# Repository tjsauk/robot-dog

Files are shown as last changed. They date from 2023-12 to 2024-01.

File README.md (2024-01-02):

# robot-dog
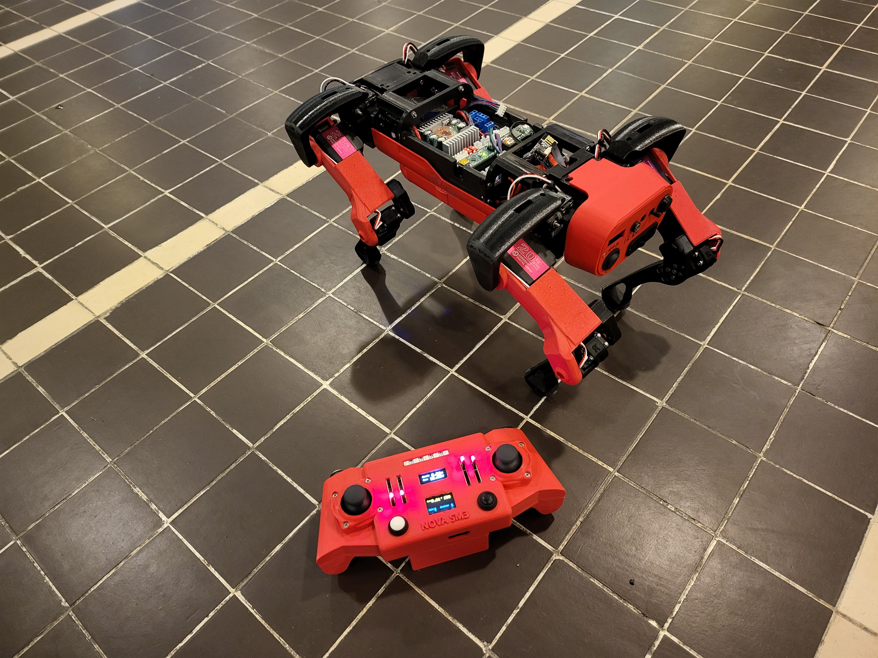
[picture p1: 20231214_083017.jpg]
The robot and the remote

Code and the documentation pdf contain spelling errors.<br>
Comments in code are partly in english and partly in finnish.<br>

Other than that the simulator works as its supposed to.<br>

Folder muokatut contains some 3D models that I have modified. <br>
-NOVA SM3 Assembly_SM3_Frame_RightTibia muokattu <-- modified tibia for the robot, attachment point for  the servo is changed to better fit the servomotors used.<br>
-cover_updated_for_Chris_Shoulder_muokattu v4 <-- modified the bearing holes to fit the bearings I used.<br>
-SM3_Frame_FrontShoulderOuter paksunnettu <-- part is made thicker and bearing holes deeper to work with the modified frame.<br>
-SM3_Frame_RearShoulderMiddle Paksunnettu levy <-- same as above.<br>
-robottikoiran jetson runko v4 <-- modified main frame part for the robot. It is made to have room for jetson nano and the components in the original design.<br>
-Assembly_Cover_HeadPanel kamera upotus v8 <-- modified the head part so that it has mounting for IMX219-83 Stereo Camera.<br>
-Ass - Speaker v5 v1 <-- is modified so that it fits to the new shoulder frame parts.<br>
-tassumuotti <- mold for casting the paws from silicone
-Paw pressure sensor contains files for the parts and couple of images of the sensors. 
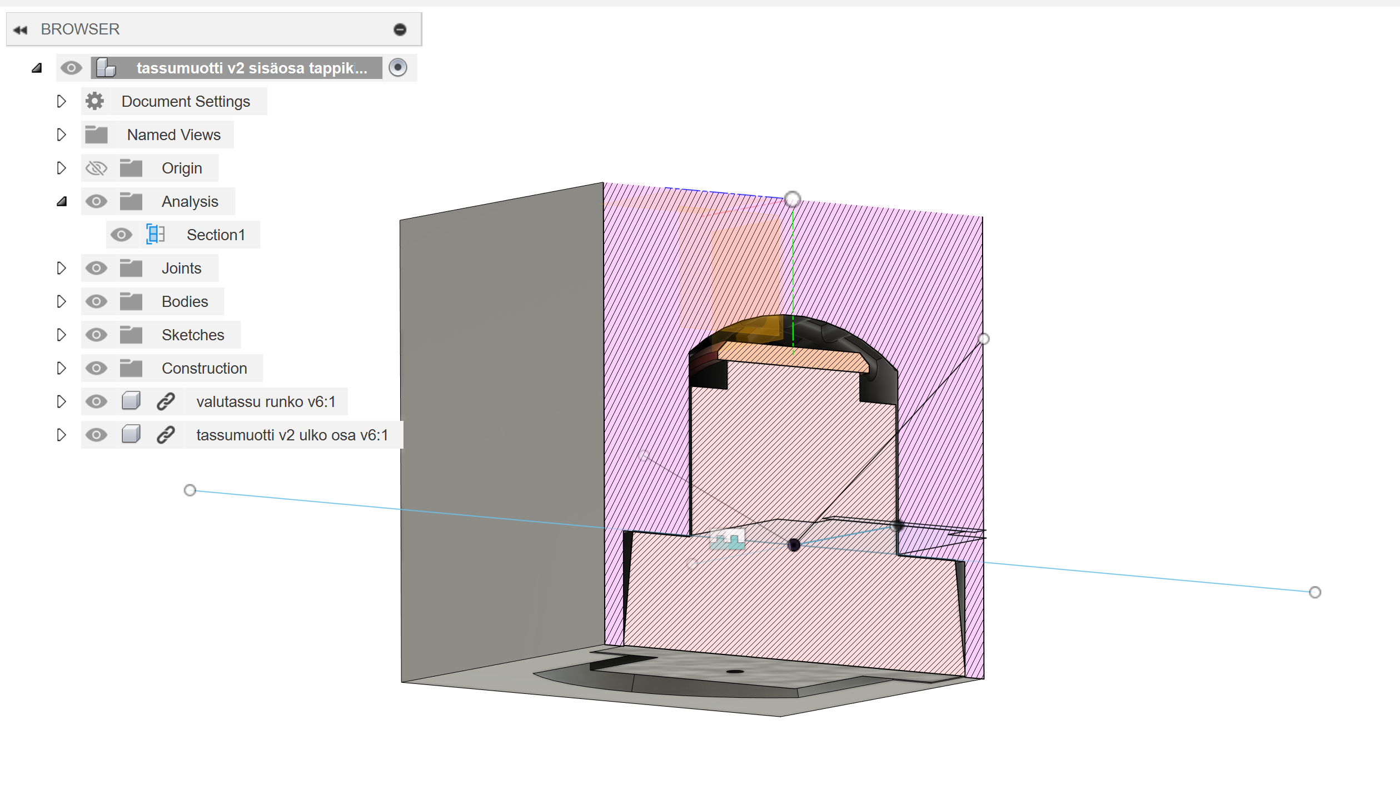
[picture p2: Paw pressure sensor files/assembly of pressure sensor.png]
Assembly of the paw mould

Here is the partnumber for the sensor from digikey 1738-SEN0293-ND

Original design can be found from here:<br>
https://github.com/cguweb-com/Arduino-Projects/tree/main/Nova-SM3<br>

Code is python version of the code that is eventually going to be in the robot. <br>

Python version works as a simulator for the behavior, so it would be easyer to implement new code with out breaking anything.<br>

dynamic_balancing_v0.1 contains the teensy 4.0 code that has all the basic functionality. It can communicate with the remote and move accordingly. The code does dynamic balancing while walking but the parameters of that are in a need of finetuning at the time this code was uploaded. <br>

To set up the code in your system follow these steps. <br>
Comment everything off from the void loop. Start by finding the zero position just by adjusting values in these lines <br>
body.mRightFront.mTibia.Attach(15, SERVO_35KG, 220.0, 10.0,89.3). Zero position is a position where coaxes are aligned and in 90 degree angle relative to the body and the axis of tibia and femur align in a straigh line going down from the body toward the ground. Basicly in zero position the robot stand with all its legs fully extended. Find this position by changing the first degree value in Attach commands. Then after the correct degrees are found its time to move those values in to the last position in the attach command. Then the first values are used to find good boot up position for the robot. <br>
The syntax of the attach goes like this body.mRightFront.mTibia.Attach(Pin id of this joint in the motor driver, Type of motor used, Home position in degrees, Home position offset,Zero position in degrees)<br>
After the zero and home is set up you can run the code inside the void loop. To make the robot move correctly you need to finetune the zero positions by putting the robot in to a walking position and compare the values in myconfig to the robots current position. Fine tune the degrees until the robot matches to the myconfig values as closely as possible, start from coax joints, continue with femurs and finally tibia. Tibia can be used to eaven out the weight distribution of the robot. <br>
To make the robot resbond to the remote you need to have the same remote or set up your own. The remote im using can be found here <br>
https://github.com/cguweb-com/Arduino-Projects/tree/cb5a4712f65acdd1623183609f027163f564fcbd/Nova-SM3/Remote%20Control <br>
My remote code v0.1 matches this teensy code so it should work with little effort. <br>

dynamic_balancing_v0.2 works with remote adjusted balancing parameters. Remote code 0.2 matches this version. <br>

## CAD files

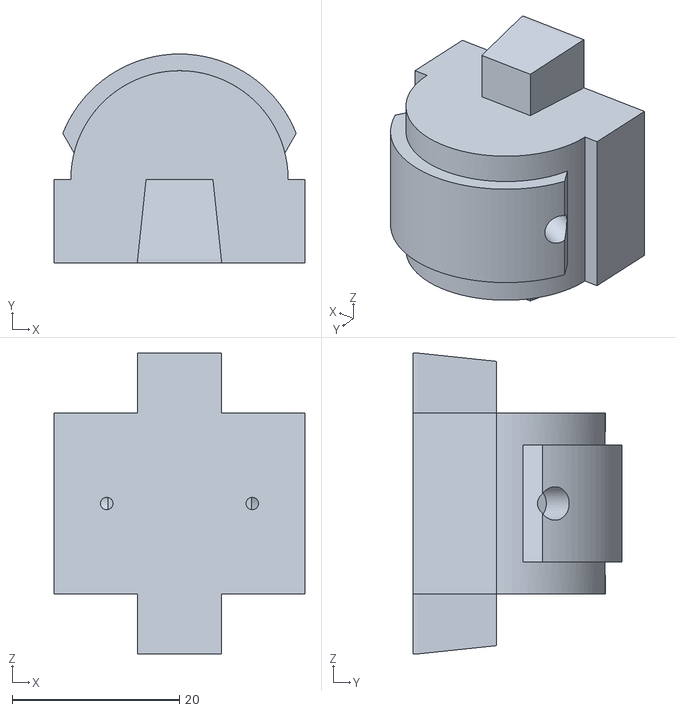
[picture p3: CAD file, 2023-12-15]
muokatut/tassumuotti v2 sisäosa tappikiinnitys v2.stl
30.0 x 25.0 x 36.0

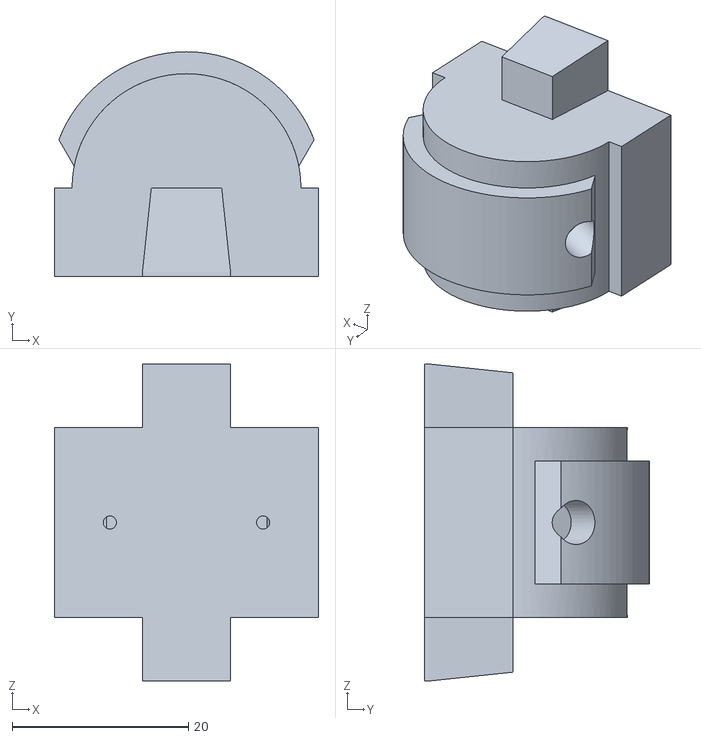
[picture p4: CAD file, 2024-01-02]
Paw pressure sensor files/tassumuotti v2 sisäosa tappikiinnitys liimausjigi v3.stl
30.0 x 25.5 x 36.0

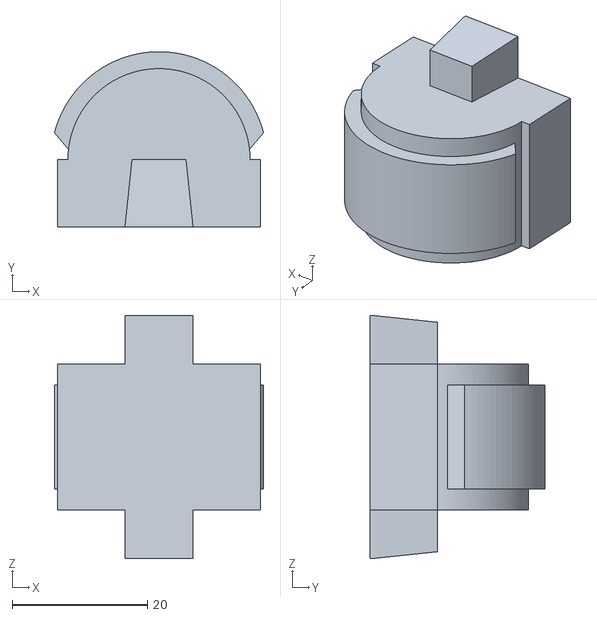
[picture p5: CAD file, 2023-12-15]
muokatut/tassumuotti v2 sisäosa v4.stl
31.0 x 26.0 x 36.0

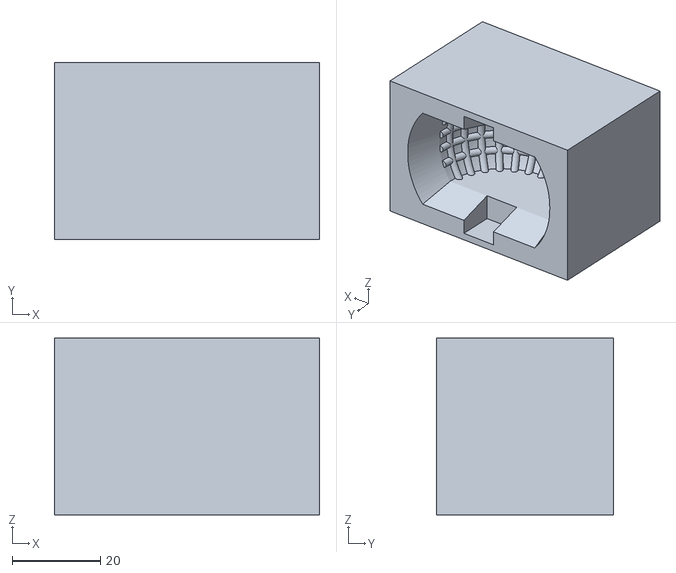
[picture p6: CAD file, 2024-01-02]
Paw pressure sensor files/tassumuotti ulko osa urilla.stl
60.0 x 40.0 x 40.0

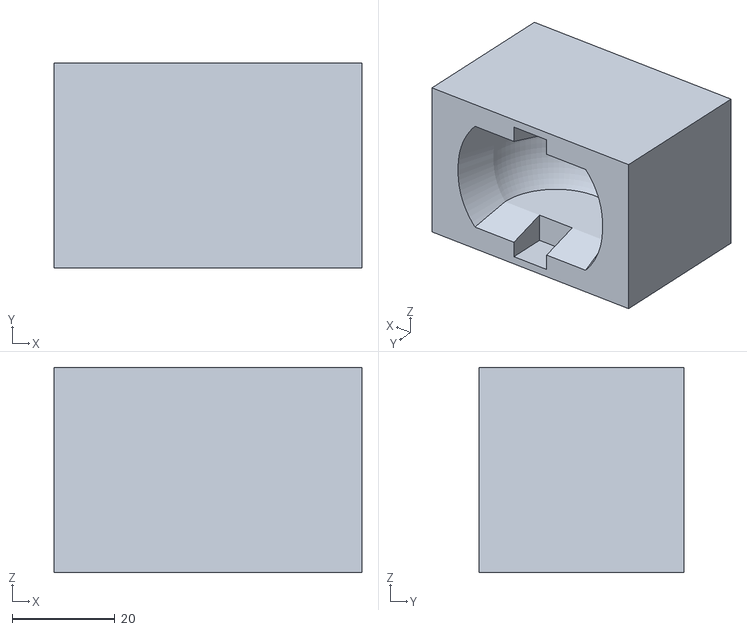
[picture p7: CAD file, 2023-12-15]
muokatut/tassumuotti v2 ulko osa v2.stl
60.0 x 40.0 x 40.0

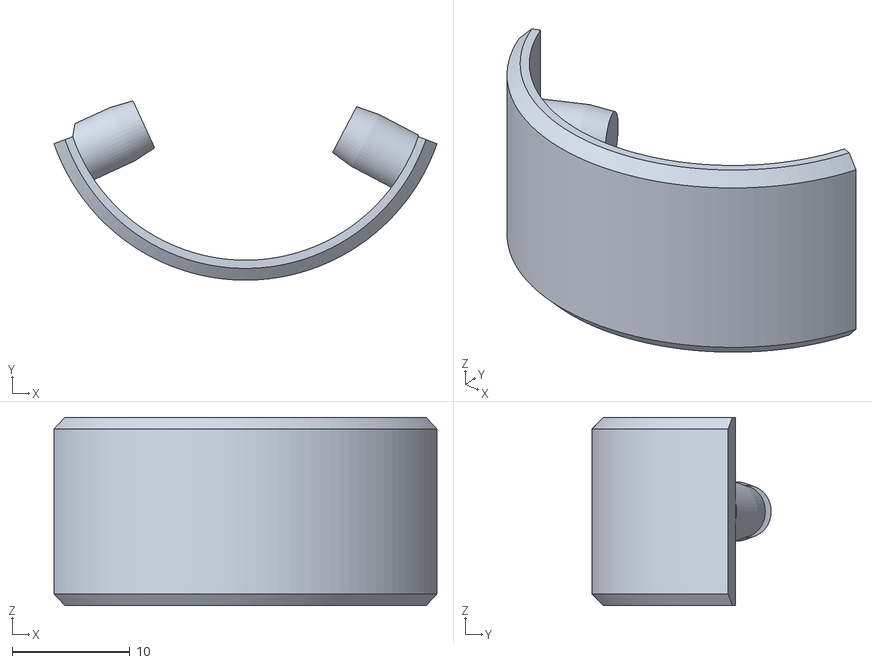
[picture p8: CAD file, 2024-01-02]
Paw pressure sensor files/valutassu runko TPU.stl
32.5 x 15.2 x 16.0

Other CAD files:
Paw pressure sensor files/tassumuotti sisäosa tappikiinnitys valuversio.stl
muokatut/Ass - Speaker v5 muokattu.f3d
muokatut/NOVA SM3 Assembly_SM3_Frame_RightTibia muokattu.f3d
muokatut/SM3_Frame_FrontShoulderOuter paksunnettu.f3d
muokatut/SM3_Frame_RearShoulderMiddle Paksunnettu levy.f3d
muokatut/robottikoiran jetson runko v4.f3d

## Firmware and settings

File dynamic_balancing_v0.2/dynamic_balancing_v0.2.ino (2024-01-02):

#include "MyAsyncServo.h"
#include "MyLeg.h"
#include "MyBody.h"
#include "MyLog.h"
#include <RF24.h>
#include "MPU6050_conf.h"

//NovaSMRemote NRF24 controller
//Pin wiring for Teensy 4.0:
//  pin 9 -> CE pin
//  pin 10 -> CSN pin
//  pin 13 -> SCK pin
//  pin 11 -> MOSI pin
//  pin 12 -> MISO pin
//  pin xx -> IRQ pin (unused)
// instantiate an object for the nRF24L01 transceiver
RF24 nrf_radio(9, 10);
unsigned int nrfInterval = 50;
unsigned long lastNRFUpdate = 0;
unsigned int remoteInterval = 50;
unsigned long lastRemoteUpdate = 0;

uint8_t address[2][6] = {"1Node", "2Node"};
bool radioNumber = 1; // 0 uses address[0] to transmit, 1 uses address[1] to transmit
const int data_num = 14;          //bytes of data to receive
bool rc_resp;
uint8_t rc_data[data_num] = {     //receive data array
  0, 0, 0, 0,                     //btn1, btn2, btn3, btn4
  0, 0,                           //sel2, sel1
  0, 0, 0, 0,                     //p1, p4, p2 , p3 index 6-9
  0, 0, 0, 0                      //lx, ly, rx, ry index 10-13
};
uint8_t tm_data[data_num] = {     //transmit data array
  0, 0, 0,                        //battery, spd, Y
  0, 0, 0,                        //x compensate, y compensate, ??
  1, 0, 0, 0,                     //Current gate, Standing up, ?? , ??
  0, 0, 0, 0                      //
};

#define BATT_MONITOR A1

// MPU6050 sensor I2C address
const int MPU = 0x68;

// Time interval in milliseconds for MPU updates
unsigned int mpuInterval = 10;
unsigned int mpuInterval_prev = 400;

// Timestamp for the last MPU update
unsigned long lastMPUUpdate = 0;

// Variables for storing the current and previous roll, pitch, and yaw values
float mroll, mpitch, myaw;
float mroll_prev, mpitch_prev, myaw_prev;

// Variables for accelerometer angles
float accAngleX, accAngleY;

// Variables for gyro angles
float gyroAngleX, gyroAngleY, gyroAngleZ;

// Base offset values for MPU
float mpu_mroll = 0.00;
float mpu_mpitch = 0.00;
float mpu_myaw = 0.00;

// Threshold value for triggering MPU changes
float mpu_trigger_thresh = 0.05;

// Timing variables for handling the sensor's updates
float elapsedTime, currentTime, previousTime;

// Flag to check if MPU is active
int mpu_is_active = 1;

// Counter variable for MPU
int mpu_c = 0;

// Instantiate the body object

MyBody body;

//----------------------------

// y akseli on pystyssä z sivuttain ja x kulkusuunnassa
void setup() {
  my_log(MYLOG_INFO, "Application started");
  

  // Attach(PWM_ID, SERVO_TYPE, HOME_DEGREE, DEGREE_CORRECTION,ZERO_DEGREE)
  //To make inverse kinematics work, change motor degree ranges correct at myasyncservo.cpp file
  //home degrees and correction term define the position the robot starts at. Start finding from the middle of your servos movement
  //zero degrees is the degree position where legs are fully extended and straight down from the body. Start allso from center.
  //Fine tune the zero degrees calibration by measuring that coax motors are in 90 degree angle relative to the frame. when robot is in standing position
  //femurs need to be calibrated next so that rear and front legs go straight relative to each other
  //then tibia is calibrated so that the standing position height is correct. Finally femur needs to be tuned so that the paw position
  //is correct measurement wise. Remember to make sure all slack in the joints is correctly positioned aka legs are under weight
  //--------------------------------------------------------
  body.mRightFront.mTibia.Attach(15, SERVO_35KG, 220.0, 10.0,89.3);//posi akselin suuntaan myötäpäivään 83
  body.mRightFront.mFemur.Attach(14, SERVO_20KG, 100.0, 0.0,170.8);
  body.mRightFront.mCoax.Attach(13, SERVO_20KG, 135.0, 6.0,139.0);//positive drives legs end to right
 

  body.mRightRear.mTibia.Attach(6, SERVO_35KG, 220.0, 10.0,90.0);//pos aks suun myöt päiv
  body.mRightRear.mFemur.Attach(5, SERVO_20KG, 100.0, -15.0,172.3);//smaller number lifts knee up
  body.mRightRear.mCoax.Attach(4, SERVO_20KG, 135.0, 3.0,139.0);//positive drives legs end to right
  
  
  body.mLeftFront.mTibia.Attach(9, SERVO_35KG, 220.0, 3.0,87.9);//suurempi on enemmän koukussa. suora koti oli 85. koukku koti oli 220 ja 3
  body.mLeftFront.mFemur.Attach(10, SERVO_20KG, 100.0, -20.0,172.9);//pienempi on takana ylhäällä. suora koti oli 110. koukku koti oli 100 ja -20
  body.mLeftFront.mCoax.Attach(11, SERVO_20KG, 135.0, -9.0,135.0);//positive drives legs end to right
  
  
  body.mLeftRear.mTibia.Attach(2, SERVO_35KG, 220.0, 3.0,85.1);//nega aks suunt myötäpäivään
  body.mLeftRear.mFemur.Attach(1, SERVO_20KG, 100.0, -26.0,172.2);//110 muuttamaton
  body.mLeftRear.mCoax.Attach(0, SERVO_20KG, 135.0, -12.0,138.0);//positive drives legs end to right
 

  
  // PHYSICAL LIMITS IN DEGREES 
  //----------------------------
  body.mLeftFront.mTibia.SetLimits(80.0, 270.0); 
  body.mLeftRear.mTibia.SetLimits(80.0, 270.0); 
  body.mRightFront.mTibia.SetLimits(80.0, 270.0); 
  body.mRightRear.mTibia.SetLimits(80.0, 270.0); 
  
  body.mLeftFront.mFemur.SetLimits(0.0, 270.0);
  body.mRightFront.mFemur.SetLimits(0.0, 270.0);
  body.mLeftRear.mFemur.SetLimits(0.0, 270.0);
  body.mRightRear.mFemur.SetLimits(0.0, 270.0);

  body.mLeftFront.mCoax.SetLimits(50.0, 170.0);
  body.mRightFront.mCoax.SetLimits(50.0, 170.0);
  body.mLeftRear.mCoax.SetLimits(50.0, 170.0);
  body.mRightRear.mCoax.SetLimits(50.0, 170.0);
  
  pinMode(LED_BUILTIN, OUTPUT);
  
  // Put synchronously body in home
 
  body.home();

  delay(2000);

    //init NRF24 wireless
  
    if (!nrf_radio.begin()) {
      Serial.println(F("radio hardware is not responding!!"));
      while (1) {}
    } else {
      nrf_radio.setPALevel(RF24_PA_LOW);
      nrf_radio.setPayloadSize(sizeof(rc_data));
      nrf_radio.setChannel(124);
      nrf_radio.openReadingPipe(1, address[!radioNumber]);
      nrf_radio.enableAckPayload();
      nrf_radio.startListening();
      nrf_radio.writeAckPayload(1, &tm_data, sizeof(tm_data)); // pre-load data      if (debug8) Serial.println(F("radio hardware is ready and listening!"));
    }

     // Initialize the MPU6050 sensor

    // Start the Wire library and communicate with the MPU6050
    Wire1.begin();

    // Read the WHO_AM_I register to confirm device identity
    uint8_t c = readByte(MPU6050_ADDRESS, WHO_AM_I_MPU6050);
    delay(1000); // Delay for stability

    // Check if the read identity is correct (0x68)
    if (c == 0x68) {
        // Perform a self-test on the MPU6050
        MPU6050SelfTest(SelfTest);

        // Check if self-test values are within acceptable ranges
        if (SelfTest[0] < 1.0f && SelfTest[1] < 1.0f && SelfTest[2] < 1.0f &&
            SelfTest[3] < 1.0f && SelfTest[4] < 1.0f && SelfTest[5] < 1.0f) {
            // Calibrate the gyro and accelerometers and initialize MPU6050 settings
            calibrateMPU6050(gyroBias, accelBias);
            initMPU6050();
        }
    }
}
  
  



void nrf_ack() {

    //set data
    int sensorValue = analogRead(BATT_MONITOR);//in a skale from 0 to 1023
    double voltage = (sensorValue * (3.3 / 1023.00) *(0.985+4.668))/0.985*1.325; 
    tm_data[0] = int(voltage*10);
    //tm_data[0] = 0;//bv;
    //tm_data[1] = 0;//spd;
    tm_data[2] = int(body.getHeight());//sound_vol;
    //tm_data[3] = 0;//move_steps;
    //tm_data[4] = 6;//(step_weight_factor_front * 100);
    //tm_data[5] = 6;//(step_weight_factor_rear * 100);
    //tm_data[6] = 0;//remote_select;
    //tm_data[7] = 3;//start_mode;
    
  
    nrf_radio.writeAckPayload(1, &tm_data, sizeof(tm_data)); // load the payload for the next time
}

bool nrf_check() {
  bool resp = false;
  uint8_t pipe;

  if (nrf_radio.available(&pipe)) {
    uint8_t bytes = nrf_radio.getPayloadSize();
    nrf_radio.read(&rc_data, bytes);
    resp = true;

    //send data as acknowledgement
    nrf_ack();


  }
  lastNRFUpdate = millis();

  return resp;
}

void get_mpu() {

  if(readByte(MPU6050_ADDRESS, INT_STATUS) & 0x01) {  // check if data ready interrupt
    readAccelData(accelCount);  // Read the x/y/z adc values
    getAres();
    
    //Acceleration values in m/s with correction to system coordinates
    // Adjust the axis readings to match the system's coordinate and convert to m/s^2
        ax = -((float)accelCount[0] - accelBias[0]) * aRes * 9.81; // Reverse X-axis and convert to m/s^2
        az = ((float)accelCount[1] - accelBias[1]) * aRes * 9.81;  // Map Y to Z and convert to m/s^2
        ay = -((float)accelCount[2] - accelBias[2]) * aRes * 9.81; // Map Z to Y, invert it and convert to m/s^2

    readGyroData(gyroCount);  // Read the x/y/z adc values
    getGres();
 
    // Adjust the gyroscope axis readings to match the system's coordinate
    gx = -((float)gyroCount[0] * gRes - gyroBias[0]); // Reverse X-axis
    gz = ((float)gyroCount[1] * gRes - gyroBias[1]);  // Map Y to Z
    gy = -((float)gyroCount[2] * gRes - gyroBias[2]); // Map Z to Y and invert


  }  
    
  //on init mpu, save offsets as defaults for resetting MPU position
  if (mpuInterval != mpuInterval_prev){
    mpuInterval = mpuInterval_prev;
    mpu_mroll = mroll;
    mpu_mpitch = mpitch;
    mpu_myaw = myaw;

    
  }

  lastMPUUpdate = millis();
}

void test3(unsigned long now_mills)
{
  static int test_phase = 0;
  static unsigned int wait_until = 1000;
  
 
  if (now_mills < wait_until)
   { return;
   }
  else if (test_phase == 0)
  {
    body.setGait(GAIT_WALK); // select WALK mode GAIT_WALK
    body.GoWalkPosition(now_mills, 900, 0.3); // start stand-up at time delta=0ms then 1000ms pause (the stand-up duration is set to 900ms then 100ms do nothing) 
    //body.GoTestPosition(now_mills, 900, 0.3);
    //GoZeroPosition(unsigned long mills, unsigned long duration, double ramp)
    //body.GoZeroPosition(now_mills, 900, 0.3);
    test_phase++;
    wait_until = now_mills + 3000; // wait 2s (where the movement home->walk position elapse 900ms)
    return;
  }
    else if (test_phase == 1)
  {
    //WalkDirection(double velocity, double degree_x, double  degree_y, double degree_z, double x, double y, double z, double ramp)
    body.WalkDirection(0.04, 0.0, 0, 0, 1, 0, 0, 0.3, 0);//nopeus m/s , x kääntö suunta,y kääntö suunta,zkääntö suunta, x suunnan nopeus 0-1, y korkeus +- kävely asennosta, z nopeus 0-1
   
    
    test_phase++;
    wait_until = now_mills + 50000; // walk for 2s
    return;
  }
    
  
  else if (test_phase == 2)/////////////
  {
    body.WalkDirection(0.25, 0, 0, 0, 0, 0, 0, 0.3 , 2);//last integer 0 means walk or move, 1 is go home 
    body.GoWalkPosition(now_mills, 900, 0.3);
    test_phase++;
    wait_until = now_mills + 1000; // stay stopped for 1s
    return;
  }
  
  
}

double reMapJoystic(double val, double midvalue)
{
  double deadzone = 5;// +- 5 from center
  double result = 0.0;
  
  if (val > (midvalue - deadzone) && val < (midvalue + deadzone)) {
    return 0.0;
  } else if (val > (midvalue + deadzone)) { // from 0 to 1
    double coef = 255 - (midvalue + deadzone); // Range of values from dead zone to high max coefficient converting it to range 0-1
    result = ((double)(val - (midvalue + deadzone))*(1 / coef));
    return result;
  } else {//if (val < (midvalue - deadzone)) 
    result = (double)val * (1.0 / (midvalue - deadzone))-1;
    return result;
  }
}



void loop() {
  static unsigned int last_mills = 0;//Time of next command update
  nrf_check();//receive and send remote data
  get_mpu();
  unsigned long now_mills = millis();//current time
  static int isSitting = 0;
  static int isGivingPaw = 0;
  static int captureIMUzero = 0;
  
    if (now_mills >= last_mills)//time needs to be greater or equal of the set limit
  {
    //Take measurements from gyro when at home position
    if (!captureIMUzero){
      body.setIMUzero();
      captureIMUzero = 1;
    }
    //luetaan sel1 tilaa joka aktivoituessaan asettaan tm_data[7] = 3;//start_mode; joko nollaksi tai ykköseksi
    //
    
    if (int(rc_data[5])){//Left select pressed initialise or unitialise
    
      if (tm_data[7]){//if at walk position go to home
        body.GoHome(now_mills, 900, 0.3);
        tm_data[7] = 0;
        isSitting = 0;
        isGivingPaw = 0;
        captureIMUzero = 0;
        
      }else{
        body.GoWalkPosition(now_mills, 900, 0.3);
        tm_data[7] = 1;
        isSitting = 0;
        isGivingPaw = 0;
        
      }
      last_mills = now_mills+900;
    }else if (int(rc_data[4]) ){//Right select switch pressed. Change walking gate
      if (int(tm_data[6]) == 2){//Was in trot, going to walk
          body.setGait(GAIT_WALK);//GAIT_TROT
          tm_data[6] = 1;
      }else{//Was in walk going to trot
        body.setGait(GAIT_TROT);//
          tm_data[6] = 2;
      }
      last_mills = now_mills;
    }else if (int(rc_data[0])){//button 0 go sit position
      if (isSitting && !isGivingPaw){
        body.GoWalkPosition(now_mills, 900, 0.3);
        tm_data[7] = 1;
        isSitting = 0;
        isGivingPaw = 0;
        
      }else if (isSitting && isGivingPaw){
        body.GoSitPosition(now_mills, 900, 0.3);
        tm_data[7] = 0;
        isSitting = 1;
        isGivingPaw = 0;
        
      }else{
        body.GoSitPosition(now_mills, 900, 0.3);
        tm_data[7] = 0;
        isSitting = 1;
        isGivingPaw = 0;
        
      }
      
      last_mills = now_mills+900;
    }else if (int(rc_data[1]) && isSitting){//if sitting give paw when button 1 is pressed
      body.GoGivePawPosition(now_mills, 900, 0.3);
      isGivingPaw = 1;
      last_mills = now_mills+900;
      
    }
    else if (tm_data[7]) //is initialised
    {
      //joysticks
      double lx = reMapJoystic(int(rc_data[10]),147);
      double ly = reMapJoystic(int(rc_data[11]),109);
      double rx = reMapJoystic(int(rc_data[12]),147);
      double ry = reMapJoystic(int(rc_data[13]),109);
      //Slide pots from left to right
      //first is going to be x axis roll control
      //second
      double spd = map(double(rc_data[8]),0,255,0.01,0.4);//second pot
      tm_data[1] = int(spd*100);
      int yy = WALK_POSITION_FRONT_Y;//Y height goal from remote
      double xr = 0.0; // roll in x axis
      if (true)//use pots 3 and 4 for balancing parameters
      {
          int xc = map(int(rc_data[9]),0,255,0,40);//third pot controlling balance compensation
          tm_data[3] = xc;//balance compensation in x axis 
      
          int yc = map(int(rc_data[7]),0,255,0,20);//Fourth pot
          tm_data[4] = yc;//balance compensation in y axis 
          body.setBalancing(xc, yc);

          yy = map(int(rc_data[6]),0,255,125,185);//First pot Changing y height 
          //tm_data[2] = body.getHeight();//balance compensation in y axis 
      }else{//rc_data[9] is the third pot and rc_data[7] is the fourth pot
        //Here goes the other configuration of pots 1, 3 and 4 
          yy = map(int(rc_data[7]),0,255,125,185);//Fourth pot
          xr = map(int(rc_data[6]),0,255,-1,1);
          if (abs(xr) == 0.05){//rotation over x axis needs some dead zone
            xr = 0.0;
          }
      }

      double ym = 0.0;//up or down in y axis control variable
      double yrel = yy/body.getHeight();
      if (yrel > 1.01){//goal is larger than current 1.005 min value
        ym = map(yrel,1.01,1.5,0.0,-1.0);
      }else if (yrel < 0.99){//current is larger than goal 0.995 max value 
        ym = map(yrel,0.65,0.99,1.0,0.0);
      }else{
        ym = 0.0;
      }

      
      if (lx == 0 && ly == 0 && rx == 0 && ry == 0 && ym == 0.0 && xr == 0)//All movement parameters 0
      {
        //body.GoWalkPosition(now_mills, 900, 0.3);//GoStandPosition
        body.GoStandPosition(now_mills, 900, 0.3);//
        last_mills = now_mills+900;
      }else{//movement reguired
        if (spd > 0.04){//this should scale the tilt on the left joystick so that the maximum speed of movement corresponds speed achieved when spd is 0.04
          ly = ly*0.04/spd;
        }
        body.WalkDirection(spd, xr, lx, ly, ry, ym, rx, 0.3, 0);
        body.PositionUpdate(now_mills);
        last_mills = now_mills;
      }

    }
    

    //test3(now_mills);
   
    //COMcalibrate(now_mills);
    //body.update(now_mills);
    //body.GoCOMposition(now_mills, 400, 0.3);
    
    
  }
  
 body.update(now_mills);
//if(millis() - lastMPUUpdate > mpuInterval) get_mpu();
}

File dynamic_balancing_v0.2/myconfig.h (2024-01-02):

#ifndef _config_h
#define _config_h

// Enable serial log
// comment out to disable
#define LOG_ENABLED
#define LOG_LEVEL MYLOG_INFO

#define DEBUG_MODE 0//0= not used, 1= print walk cycle controls and info

#define COAX_SIZE 70.0
#define FEMUR_SIZE 106.5
#define TIBIA_SIZE 116.0

#define WALK_POSITION_FRONT_X -22.0
#define WALK_POSITION_REAR_X -22.0

#define WALK_POSITION_FRONT_Y 155.0//x =6 y = 170  x=3 y=160 x=1 y= 150
#define WALK_POSITION_REAR_Y 155.0

//Walk position Z offset is given as distance away from body. Positive is away is below the body
#define WALK_POSITION_Z 20.0

#define Y_STEP_SIZE -20.0//amount of lenght in one walk cycle that body can go up and down

#define X_STEP_ANGLE 10.0 //amount of degrees the body can rotate in one walk cycle
#define Z_STEP_ANGLE 10.0

#define BODY_WIDTH 78.0
#define BODY_LENGTH 282.0

#define COM_X_OFFSET 5.0
#define COM_Z_OFFSET 0.0
#define COM_WEIGHT 80.0
#define REAR_M 2673.0
#define FRONT_M 1492.0

#define BALANCE_SAFETY_MARGIN 30.0

#define MIN_TURN_RADIUS 150.0
#define MAX_TURN_RADIUS 5000.0//in millimeters

#define STEP_SIZE 120.0
#define STEP_SWING_HEIGHT_FRONT 25.0
#define STEP_SWING_HEIGHT_REAR 25.0
#define STEP_STANCE_HEIGHT_FRONT 0.0
#define STEP_STANCE_HEIGHT_REAR 0.0
#define STEP_STANCE_TIME_PERCENTAGE 0.75
 

#endif // _config_h

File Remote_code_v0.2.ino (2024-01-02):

/*
 * 
 *   NovaSM3 Remote - a Spot-Mini Micro clone Remote Control
 *   Version: 5.2
 *   Version Date: 2021-10-26
 *   
 *   Author:  Chris Locke - cguweb@gmail.com
 *   Nova's website:  https://novaspotmicro.com
 *   GitHub Project:  https://github.com/cguweb-com/Arduino-Projects/tree/main/Nova-SM3
 *   YouTube Playlist:  https://www.youtube.com/watch?v=00PkTcGWPvo&list=PLcOZNHwM_I2a3YZKf8FtUjJneKGXCfduk
 *   
 *   RELEASE NOTES:
 *
 *   DEV NOTES:
 *     
 *   =============================================================
 *     
 *   Copyright (c) 2020-2021 Christopher M. Locke and others
 *   Distributed under the terms of the MIT License. 
 *   SPDX-License-Identifier: MIT
 *   
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
 *      
*/


float VERSION = 5.2;

int debug = 0;                    //general debugging
int debug2 = 0;                   //nrf24 serial comm
int debug3 = 0;                   //controls to serial
int debug4 =  0;                  //controls interactive test mode 
int debug5 =  0;                  //battery monitor 
int plotter = 0;                  //control to plotter (also set debug3 = 1)

byte nrf_active = 1;
byte batt_active = 1;             //activate battery level monitoring
byte activity_active = 0;         //activate inactivity monitor / sleep mode

#include <SPI.h>
#include <RF24.h>
#include <Wire.h>
#include <Adafruit_NeoPixel.h>
#include <Adafruit_GFX.h>
#include <Adafruit_SSD1306.h>

//========================================
//  NRF24 Pin Wiring for Arduino Mega/Nano:
//  pin 7/7 -> CE pin
//  pin 8/8 -> CSN pin
//  pin 52/13 -> SCK pin
//  pin 51/11 -> MOSI pin
//  pin 50/12 -> MISO pin
//  pin xx -> IRQ pin (unused)
//========================================
// NRF24L01 transceiver setup
RF24 radio(7, 8); // Initialize the RF24 radio object with pins 7 and 8 for CE and CSN respectively
unsigned int nrfInterval = 60; // Interval in seconds for NRF updates
unsigned long lastNRFUpdate = 0; // Timestamp of the last NRF update
uint8_t address[][6] = {"1Node", "2Node"}; // Addresses for the NRF nodes
bool radioNumber = 0; // Flag to select which address to use for transmitting (0 or 1)
const int data_num = 14; // Number of elements in data arrays
bool tm_resp; // Response flag for transmission
uint8_t tm_data[data_num] = { // Transmit data array initialization
  0, 0, 0, 0, // btn1, btn2, btn3, btn4
  0, 0, // sel1, sel2
  0, 0, 0, 0, // p1, p2, p3, p4
  0, 0, 0, 0 // lx, ly, rx, ry
};

// DEV: Setup for currently unused two-way communication
uint8_t rc_data[data_num] = { // Receive data array initialization
  0, 0, 0, // battery, spd, Y
  0, 0, 0, // 
  1, 0, 0, 0, // Current gate, Standing up
  0, 0, 0, 0 // Unused elements
};

// Definitions for slide potentiometer pins
#define POT1_PIN A8
#define POT2_PIN A9
#define POT3_PIN A10
#define POT4_PIN A11

// Variables for potentiometer percentage values and their previous states
int per1, per2, per3, per4; // Current percentage values of pots
int pper1, pper2, pper3, pper4; // Previous percentage values of pots

// Variables for reading the potentiometer values and their previous states
int p1 = 0, p1p = 0; // Current and previous reading of POT1
int p2 = 0, p2p = 0; // Current and previous reading of POT2
int p3 = 0, p3p = 0; // Current and previous reading of POT3
int p4 = 0, p4p = 0; // Current and previous reading of POT4
int pot_slack = 10; // Threshold for potentiometer change detection
int pot_min = 0, pot_max = 255; // Min and max values for potentiometer mapping


// Joystick related variables

// Center deadzone values for both joysticks
int jstick_center[2] = {12, 12}; // Array holding the deadzone threshold for each joystick

// Minimum and maximum values for generic joystick mapping
int j_min = 0; // Minimum value for joystick position mapping
int j_max = 255; // Maximum value for joystick position mapping
// Note: If sticks are oriented oppositely to this configuration, swap j_min and j_max

// Pin definitions for the right joystick
#define RJX_PIN A4 // Right Joystick X-axis pin
#define RJY_PIN A5 // Right Joystick Y-axis pin
int rj_min = 0; // Minimum raw value for right joystick
int rj_max = 1023; // Maximum raw value for right joystick
// Note: If right joystick is oriented oppositely, swap rj_min and rj_max

// Pin definitions for the left joystick
#define LJX_PIN A6 // Left Joystick X-axis pin
#define LJY_PIN A7 // Left Joystick Y-axis pin
int lj_min = 0; // Minimum raw value for left joystick
int lj_max = 1023; // Maximum raw value for left joystick
// Note: If left joystick is oriented oppositely, swap lj_min and lj_max

// The values j_min, j_max, rj_min, rj_max, lj_min, and lj_max are used for mapping
// the raw joystick input values (which can vary based on hardware specifics) to a
// standard range that the rest of the program can consistently work with.


//rgb leds (5)
#define LED_STRIP_PIN 2
#define LED_STRIP_NUM 5
Adafruit_NeoPixel led_strip = Adafruit_NeoPixel(LED_STRIP_NUM, LED_STRIP_PIN, NEO_GRB + NEO_KHZ800);
unsigned int rgbInterval = 45;
unsigned long lastRGBUpdate = 0;
int rgb_del = 256;
int current_led = 0;
int fadeStep = 0;
int fade_steps = 400;
int fade_back = 1;
int pattern = 0;                  //set which light pattern is used
int pattern_int = 400;            //set pattern delay between
int pattern_cnt = 3;              //set number of loops of pattern
int pattern_step = 0;
int cur_rgb_val1[3] = {55, 0, 200};
int cur_rgb_val2[3] = {125, 125, 0};
int rgb_num = 99;
int rgb_bright = 25;
byte set_led[5] = {0, 0, 0, 0, 0};

// Button related variables

// "Fire" buttons (4)
#define BTN1_PIN 3 // Pin number for left front fire button
#define BTN2_PIN 5 // Pin number for right front fire button
#define BTN3_PIN 4 // Pin number for left back fire button
#define BTN4_PIN 6 // Pin number for right back fire button

int b1 = 0; // Current state of left front fire button
int b1p = 0; // Previous state of left front fire button
int b2 = 0; // Current state of right front fire button
int b2p = 0; // Previous state of right front fire button
int b3 = 0; // Current state of left back fire button
int b3p = 0; // Previous state of left back fire button
int b4 = 0; // Current state of right back fire button
int b4p = 0; // Previous state of right back fire button

// The variables b1, b2, b3, b4 hold the current state (pressed or not) of each fire button,
// while b1p, b2p, b3p, b4p keep track of their previous states for change detection.

// Select / Stop buttons (2)
#define SEL1_PIN 9  // Pin number for left green select/stop button
#define SEL2_PIN 10 // Pin number for right red select/stop button

int s1 = 0; // Current state of left green select/stop button
int s1p = 0; // Previous state of left green select/stop button
int s2 = 0; // Current state of right red select/stop button
int s2p = 0; // Previous state of right red select/stop button
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

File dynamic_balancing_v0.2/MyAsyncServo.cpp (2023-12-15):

#include <string.h>

#include "MyAsyncServo.h"
#include "MyLog.h"

bool MyAsyncServo::initialised = false;
Adafruit_PWMServoDriver MyAsyncServo::pwm = Adafruit_PWMServoDriver(0x40);

#define SERVO_FREQ 60
#define OSCIL_FREQ 25000000

MyAsyncServo::MyAsyncServo()
{
	mId = -1;
	mTargetDegree = -1;
	mCurrentDegree = -1;
	mCurrentPwm = 0;
	mIsMoving = false;
  mReverse = false;
  mName = NULL;
}

MyAsyncServo::~MyAsyncServo()
{
  if (mName)
    delete []mName;
}

void MyAsyncServo::setName(const char * owner, const char * name)
{
  mName = new char[strlen(owner) + strlen(name) + 2];
  
  
  sprintf(mName, "%s-%s", owner, name);
}
  
void MyAsyncServo::ActivatePWM()
{
	 my_log(MYLOG_INFO, "ActivatePWM");

	 pwm.begin();
	 pwm.setOscillatorFrequency(OSCIL_FREQ);
	 pwm.setPWMFreq(SERVO_FREQ);

   my_log(MYLOG_INFO, "PWM intialized");

   delay(500);
}

void MyAsyncServo::Attach(int id, int srv_type, double home, double correction, double type)
{
	if (!initialised)
	{
		ActivatePWM();
		initialised = true;
	}

	mId = id;

	mHome = home;
  mCorrection = correction;
  
  
  mZero = type;
  
  
   

	if (srv_type == SERVO_20KG)
	{
		mPwmMin = 120;//was 120
		mPwmMax = 590;

		mDegreeRange = 270;//was 180.0;
	}
	else // SERVO_35KG
	{
		mPwmMin = 140;
		mPwmMax = 590;

		mDegreeRange = 270.0;
	}
}

void MyAsyncServo::write_degree(double degree)
{
	  if (mId < 0)
			return;

    degree = degree + mCorrection;

	  if (degree < 0)
		   degree = 0;
	  else if (degree > mDegreeRange)
			degree = mDegreeRange;

		mCurrentDegree = degree - mCorrection;

	  int value_in_pwm;
	  
	  if (mReverse)
	    value_in_pwm = (double)mPwmMin + ((double)mPwmMax - (double)mPwmMin) *  degree / mDegreeRange;
    else
      value_in_pwm = (double)mPwmMax - ((double)mPwmMax - (double)mPwmMin) *  degree / mDegreeRange;

		if (value_in_pwm != mCurrentPwm)
		{
			my_log(MYLOG_DEBUG, "setpwm servo %s (id %d), degree %.1f, pwm=%d", mName, mId, mCurrentDegree, value_in_pwm);

		  pwm.setPWM(mId, 0, value_in_pwm);

			mCurrentPwm = value_in_pwm;
		}
}

void MyAsyncServo::home()
{
	  my_log(MYLOG_INFO, "home servo %d", mId);

	  write_degree(mHome);
}

void MyAsyncServo::SetLimits(double low, double high)
{
	  mLimitLow = low;
		if (mLimitLow < 0.0)
			mLimitLow = 0.0;

		mLimitHigh = high;
		if (mLimitHigh > mDegreeRange)
			mLimitHigh = mDegreeRange;
}

double MyAsyncServo::CutOffDegrees(double degree)
{
	if (degree < mLimitLow)
		return mLimitLow;
	else if (degree > mLimitHigh)
		return mLimitHigh;
  return degree;
}

double MyAsyncServo::CutOffRamp(double ramp)
{
  if (ramp < 0)
    return 0;
  if (ramp > 0.4)
    return 0.4;
  return ramp;
}

void MyAsyncServo::GoHome(unsigned long mills, unsigned long duration, double ramp)
{
  StartMovement(mills, mHome, duration, ramp);
}

void MyAsyncServo::GoCenter(unsigned long mills, unsigned long duration, double ramp)
{
  StartMovement(mills, mDegreeRange / 2.0, duration, ramp);
}

void MyAsyncServo::GoZero(unsigned long mills, unsigned long duration, double ramp)
{
  StartMovement(mills, mZero, duration, ramp);
}

void MyAsyncServo::StartMovement(unsigned long mills, double degree, unsigned long duration, double ramp)
{
	degree = CutOffDegrees(degree);
  ramp = CutOffRamp(ramp);

	//my_log(MYLOG_INFO, "StartMovement %s [%.1f, %d, %.1f]", mName, degree, duration, ramp);

  mTargetDegree = degree;
  mStartDegree = mCurrentDegree;
  mStartTime = mills;
  mEndTime = mStartTime + duration;
  mRamp = ramp;

  mIsMoving = true;
}



void MyAsyncServo::update(unsigned long mills)
{
  if (mId < 0)
    return;

	if (mIsMoving)
	{
		if (mills >= mEndTime)
		{
			//my_log(MYLOG_INFO, "EndMovement %s id=%d degree=%.1f", mName, mId, getDegree());

			write_degree(mTargetDegree);
			mIsMoving = false;
		}
		else
		{
      if (mTargetDegree == mCurrentDegree)
        return;
    
      double perc = (double)(mills - mStartTime) / (double)(mEndTime - mStartTime);

		  double pos_degree;

      if (mRamp > 0.0)
      {
				double velocitymax = (mTargetDegree - mStartDegree) / (1.0 - mRamp);

				double velocity;

        if (perc < mRamp) // ramp UP
				{
					velocity = perc / mRamp *  velocitymax;

					pos_degree = mStartDegree + perc * velocity / 2.0;

          //my_log(MYLOG_DEBUG, "ContinueMovement ramp UP %s perc=%.1f, velocitymax=%.1f, velocity=%.1f, pos=%.1f", mName, 100.0*perc, velocitymax, velocity, pos_degree);
				}
				else if (perc < (1.0 - mRamp)) // constant velocity
				{
					velocity = velocitymax;

					pos_degree = mStartDegree + (mRamp / 2.0 + perc - mRamp) * velocitymax;

         //my_log(MYLOG_DEBUG, "ContinueMovement ramp CONST %s perc=%.1f, velocitymax=%.1f, velocity=%.1f, pos=%.1f", mName, 100.0*perc, velocitymax, velocity, pos_degree);
				}
				else // ramp DOWN
				{
					velocity = (1.0 - perc) / mRamp * velocitymax;

					pos_degree = mStartDegree + (1.0 - mRamp) * velocitymax - velocity * (1.0 - perc) / 2;

          //my_log(MYLOG_DEBUG, "ContinueMovement ramp DOWN %s perc=%.1f, velocitymax=%.1f, velocity=%.1f, pos=%.1f", mName, 100.0*perc, velocitymax, velocity, pos_degree);
				}
      }
      else // No ramp
      {
		    pos_degree = mStartDegree + (mTargetDegree - mStartDegree) * perc;
        
        //my_log(MYLOG_DEBUG, "ContinueMovement %s start=%.1f, end=%.1f, now=%d, end=%d, perc=%.1f --> %.1f", mName, mStartDegree, mTargetDegree, mills, mEndTime, 100.0*perc, pos_degree);
      }
			
			write_degree(pos_degree);
		}
	}
}
